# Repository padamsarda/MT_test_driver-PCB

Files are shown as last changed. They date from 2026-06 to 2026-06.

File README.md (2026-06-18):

# Magnetorquer Test PCB

## Overview
This PCB is designed to test different magnetorquer coils under varying operating conditions like voltage, current, and temperature.

The board uses an INA219 for current sensing and ADC voltage dividers for voltage measurement. 
It also has I²C and CAN headers so external sensors like magnetometers and temperature sensors can be connected if needed.

## Features
- DRV8871 motor driver
- INA219 current sensing
- ADC voltage measurement using voltage dividers
- USB Type-C interface
- SWD programming/debugging header
- I²C expansion header
- CAN header

## Applications
- Testing different magnetorquer coils
- Characterizing coil performance under different conditions
- Connecting external sensors for additional measurements
- Closed loop testing with magnetometers

## Notes
Designed and developed as part of **Team Anant**.

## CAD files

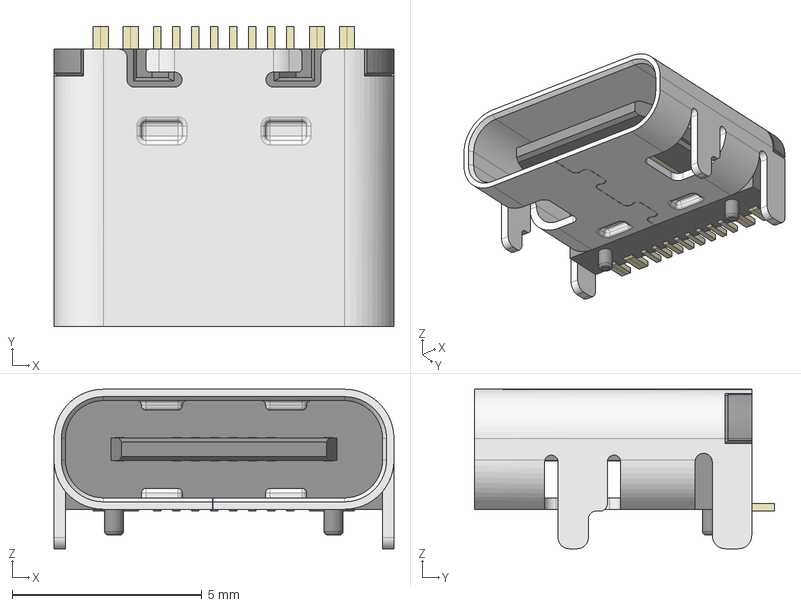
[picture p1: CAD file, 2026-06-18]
HRO_TYPE-C-31-M-12.step
8.95 x 7.90 x 4.20 mm

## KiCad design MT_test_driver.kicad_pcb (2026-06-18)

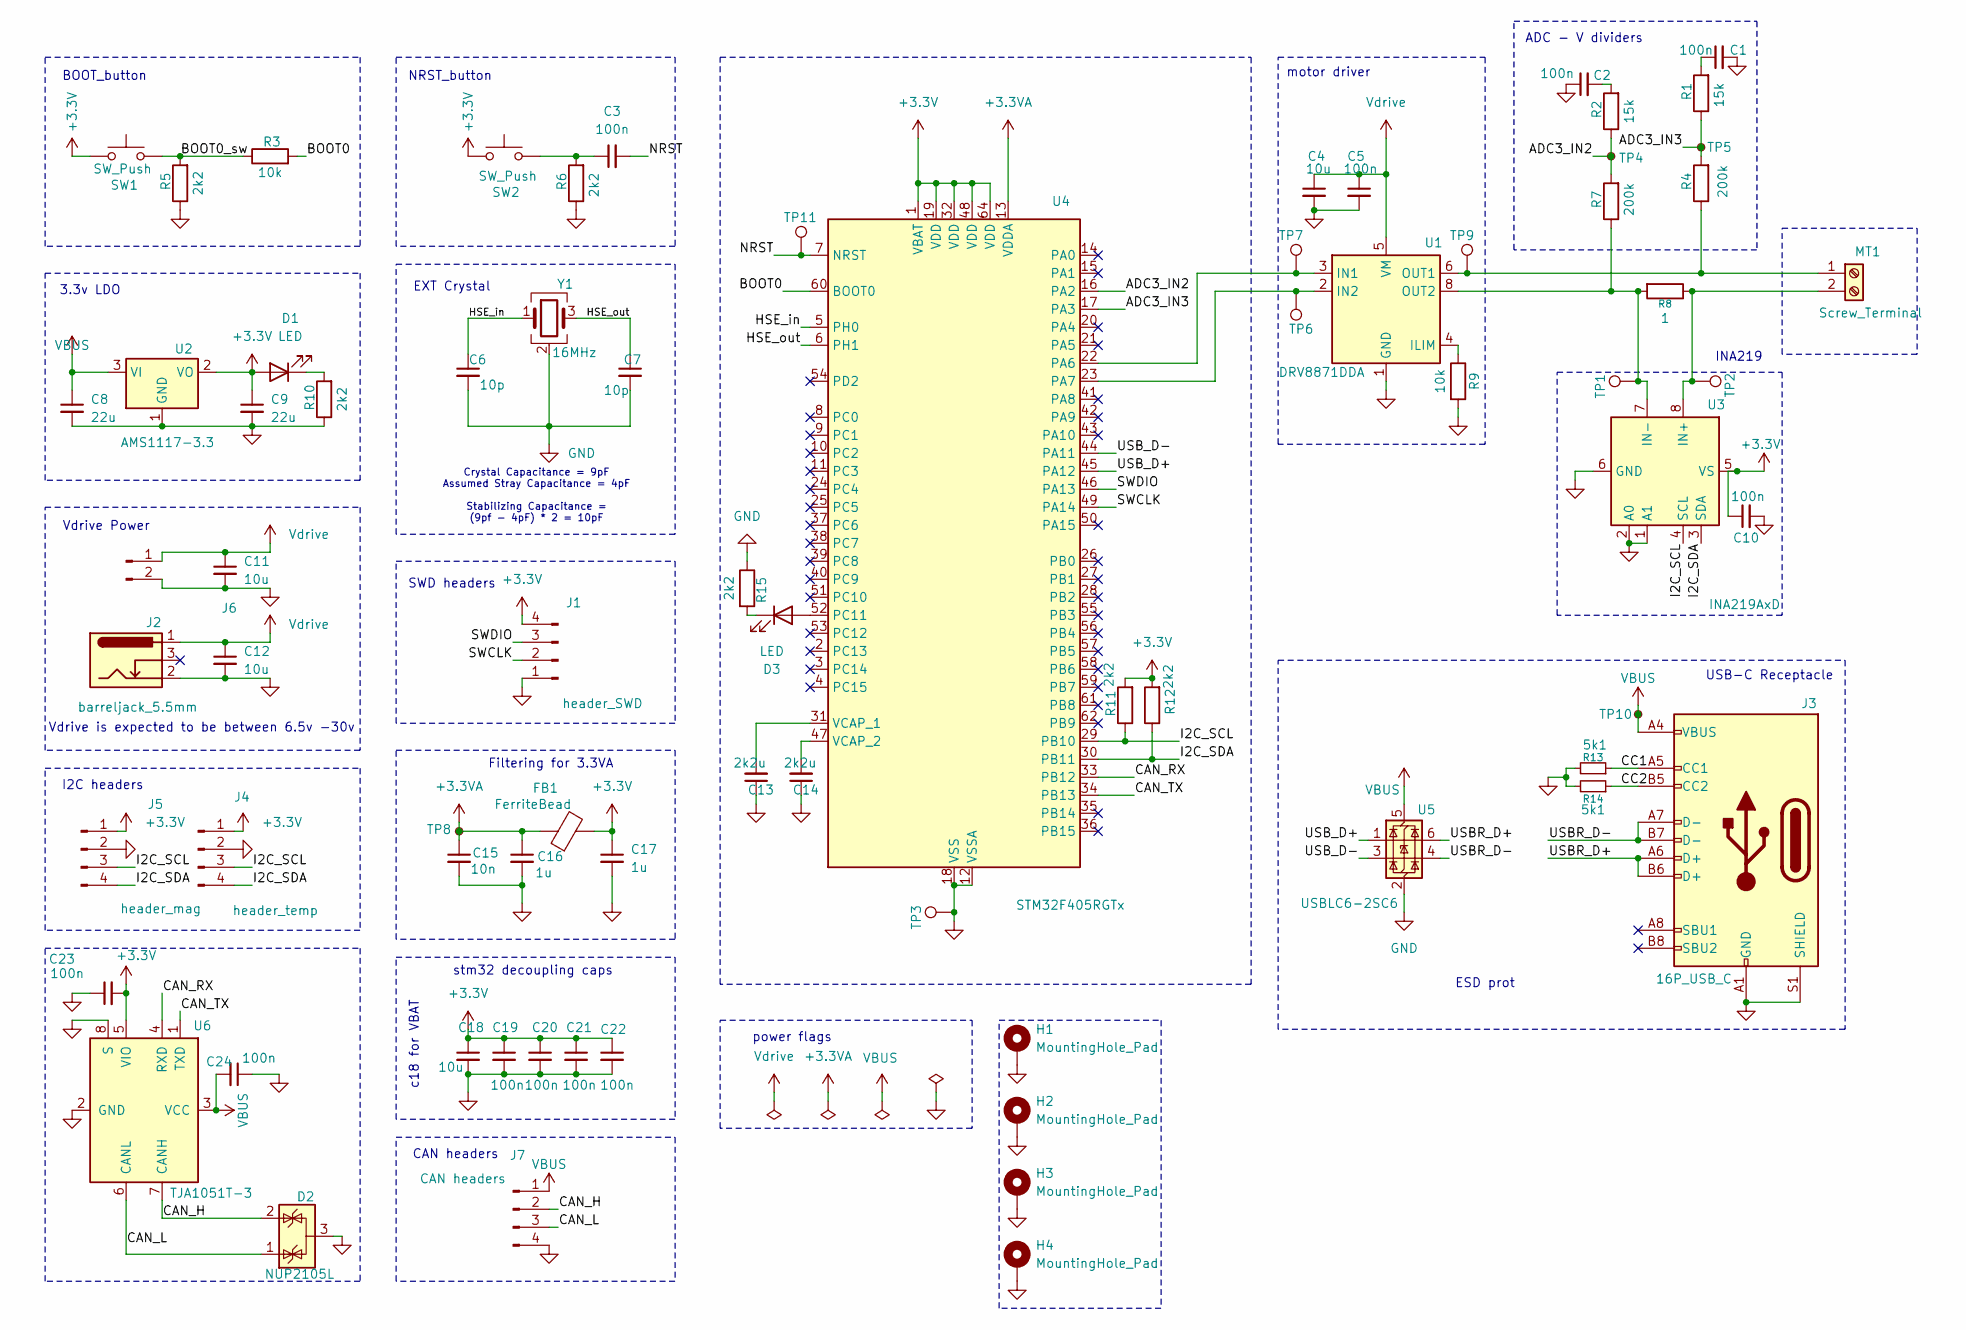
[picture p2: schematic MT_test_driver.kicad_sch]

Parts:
C1, C2, C3, C5, C10, C19, C20, C21, C22, C23, C24: 100n; C_0805_2012Metric_Pad1.18x1.45mm_HandSolder
C4, C11, C12, C18: 10u; C_0805_2012Metric_Pad1.18x1.45mm_HandSolder
C6, C7: 10p; C_0805_2012Metric_Pad1.18x1.45mm_HandSolder
C8, C9: 22u; C_0805_2012Metric_Pad1.18x1.45mm_HandSolder
C13, C14: 2k2u; C_0805_2012Metric_Pad1.18x1.45mm_HandSolder
C15: 10n; C_0805_2012Metric_Pad1.18x1.45mm_HandSolder
C16, C17: 1u; C_0805_2012Metric_Pad1.18x1.45mm_HandSolder
D1, D3: LED; LED_0805_2012Metric_Pad1.15x1.40mm_HandSolder
D2: NUP2105L; SOT-23
FB1: FerriteBead; L_0805_2012Metric_Pad1.05x1.20mm_HandSolder
H1, H2, H3, H4: MountingHole_Pad; MountingHole_2.2mm_M2_Pad
J1: header_SWD; PinHeader_1x04_P2.54mm_Vertical
J2: barreljack_5.5mm; BarrelJack_Horizontal
J3: 16P_USB_C; USB_C_Receptacle_G-Switch_GT-USB-7010ASV
J4: header_temp; PinHeader_1x04_P2.54mm_Vertical
J5: header_mag; PinHeader_1x04_P2.54mm_Vertical
J6: header_battery; PinHeader_1x02_P2.54mm_Vertical
J7: CAN headers; PinHeader_1x04_P2.54mm_Vertical
MT1: Screw_Terminal; TerminalBlock_Phoenix_MKDS-1,5-2-5.08_1x02_P5.08mm_Horizont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
R1, R2: 15k; R_0603_1608Metric_Pad0.98x0.95mm_HandSolder
R3, R9: 10k; R_0805_2012Metric_Pad1.20x1.40mm_HandSolder
R4, R7: 200k; R_0603_1608Metric_Pad0.98x0.95mm_HandSolder
R5, R6, R10, R11, R12, R15: 2k2; R_0805_2012Metric_Pad1.20x1.40mm_HandSolder
R8: 1; R_2512_6332Metric_Pad1.40x3.35mm_HandSolder
R13, R14: 5k1; R_0805_2012Metric_Pad1.20x1.40mm_HandSolder
SW1, SW2: SW_Push; tactile switch 4.5_4.5
TP1, TP2, TP3, TP6, TP7, TP9: TestPoint; PinHeader_1x01_P2.54mm_Vertical
TP4, TP5, TP8, TP10: TestPoint_Small; TestPoint_Pad_D1.5mm
TP11: TestPoint; TestPoint_Pad_D1.5mm
U1: DRV8871DDA; Texas_HTSOP-8-1EP_3.9x4.9mm_P1.27mm_EP2.95x4.9mm_Mask2.4x3.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
U2: AMS1117-3.3; SOT-223-3_TabPin2
U3: INA219AxD; SOIC-8_3.9x4.9mm_P1.27mm
U4: STM32F405RGTx; LQFP-64_10x10mm_P0.5mm
U5: USBLC6-2SC6; SOT-23-6
U6: TJA1051T-3; SOIC-8_3.9x4.9mm_P1.27mm
Y1: 16MHz; Crystal_SMD_3225-4Pin_3.2x2.5mm_HandSoldering

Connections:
+3.3V: C9.1, C10.1, C17.1, C18.1, C19.1, C20.1, C21.1, C22.1, C23.2, D1.2 (A), FB1.2, J1.4, J4.1, J5.1, R11.2, R12.2, SW1.1, SW2.1, U2.2 (VO), U3.5 (VS), U4.1 (VBAT), U4.19 (VDD), U4.32 (VDD), U4.48 (VDD), U4.64 (VDD), U6.5 (VIO)
+3.3VA: C15.1, C16.1, FB1.1, TP8.1, U4.13 (VDDA)
/ADC3_IN2: R2.1, R7.2, TP4.1, U4.16 (PA2)
/ADC3_IN3: R1.1, R4.2, TP5.1, U4.17 (PA3)
/BOOT0: R3.2, U4.60 (BOOT0)
/BOOT0_sw: R3.1, R5.2, SW1.2
/CAN_H: D2.2 (K), J7.2, U6.7 (CANH)
/CAN_L: D2.1 (K), J7.3, U6.6 (CANL)
/CAN_RX: U4.33 (PB12), U6.4 (RXD)
/CAN_TX: U4.34 (PB13), U6.1 (TXD)
/CC1: J3.A5 (CC1), R13.1
/CC2: J3.B5 (CC2), R14.1
/HSE_in: C6.1, U4.5 (PH0), Y1.1
/HSE_out: C7.1, U4.6 (PH1), Y1.3
/I2C_SCL: J4.3, J5.3, R11.1, U3.4 (SCL), U4.29 (PB10)
/I2C_SDA: J4.4, J5.4, R12.1, U3.3 (SDA), U4.30 (PB11)
/NRST: C3.2, TP11.1, U4.7 (NRST)
/SWCLK: J1.2, U4.49 (PA14)
/SWDIO: J1.3, U4.46 (PA13)
/USBR_D+: J3.A6 (D+), J3.B6 (D+), U5.6 (I/O1)
/USBR_D-: J3.A7 (D-), J3.B7 (D-), U5.4 (I/O2)
/USB_D+: U4.45 (PA12), U5.1 (I/O1)
/USB_D-: U4.44 (PA11), U5.3 (I/O2)
GND: C1.2, C2.1, C4.2, C5.2, C6.2, C7.2, C8.2, C9.2, C10.2, C11.2, C12.2, C13.1, C14.1, C15.2, C16.2, C17.2, C18.2, C19.2, C20.2, C21.2, C22.2, C23.1, C24.1, D2.3 (A), H1.1, H2.1, H3.1, H4.1, J1.1, J2.2, J3.A1 (GND), J3.A12 (GND), J3.B1 (GND), J3.B12 (GND), J3.S1 (SHIELD), J4.2, J5.2, J6.2, J7.4, R5.1, R6.1, R9.2, R10.1, R13.2, R14.2, R15.1, TP3.1, U1.1 (GND), U1.7 (GND), U1.9 (GND), U2.1 (GND), U3.1 (A1), U3.2 (A0), U3.6 (GND), U4.12 (VSSA), U4.18 (VSS), U4.63 (VSS), U5.2 (GND), U6.2 (GND), U6.8 (S), Y1.2 (G), Y1.4 (G)
unnamed: C1.1, R1.2
unnamed: C2.2, R2.2
unnamed: C3.1, R6.2, SW2.2
unnamed: D1.1 (K), R10.2
unnamed: D3.2 (A), U4.52 (PC11)
unnamed: D3.1 (K), R15.2
unnamed: MT1.1, R4.1, TP9.1, U1.6 (OUT1)
unnamed: MT1.2, R8.1, TP2.1, U3.8 (IN+)
unnamed: R9.1, U1.4 (ILIM)
unnamed: TP7.1, U1.3 (IN1), U4.22 (PA6)
unnamed: TP6.1, U1.2 (IN2), U4.23 (PA7)
unnamed: R7.1, R8.2, TP1.1, U1.8 (OUT2), U3.7 (IN-)
unnamed: C13.2, U4.31 (VCAP_1)
unnamed: C14.2, U4.47 (VCAP_2)
VBUS: C8.1, C24.2, J3.A4 (VBUS), J3.A9 (VBUS), J3.B4 (VBUS), J3.B9 (VBUS), J7.1, TP10.1, U2.3 (VI), U5.5 (VBUS), U6.3 (VCC)
Vdrive: C4.1, C5.1, C11.1, C12.1, J2.1, J6.1, U1.5 (VM)

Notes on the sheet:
EXT Crystal
SWD headers
Filtering for 3.3VA
NRST_button
motor driver
Vdrive is expected to be between 6.5v -30v
3.3v LDO
Vdrive Power
USB-C Receptacle
I2C headers
Crystal Capacitance = 9pF Assumed Stray Capacitance = 4pF Stabilizing Capacitance = (9pf - 4pF) * 2 = 10pF
ESD prot
CAN headers
BOOT_button
c18 for VBAT
power flags
stm32 decoupling caps
ADC - V dividers
INA219

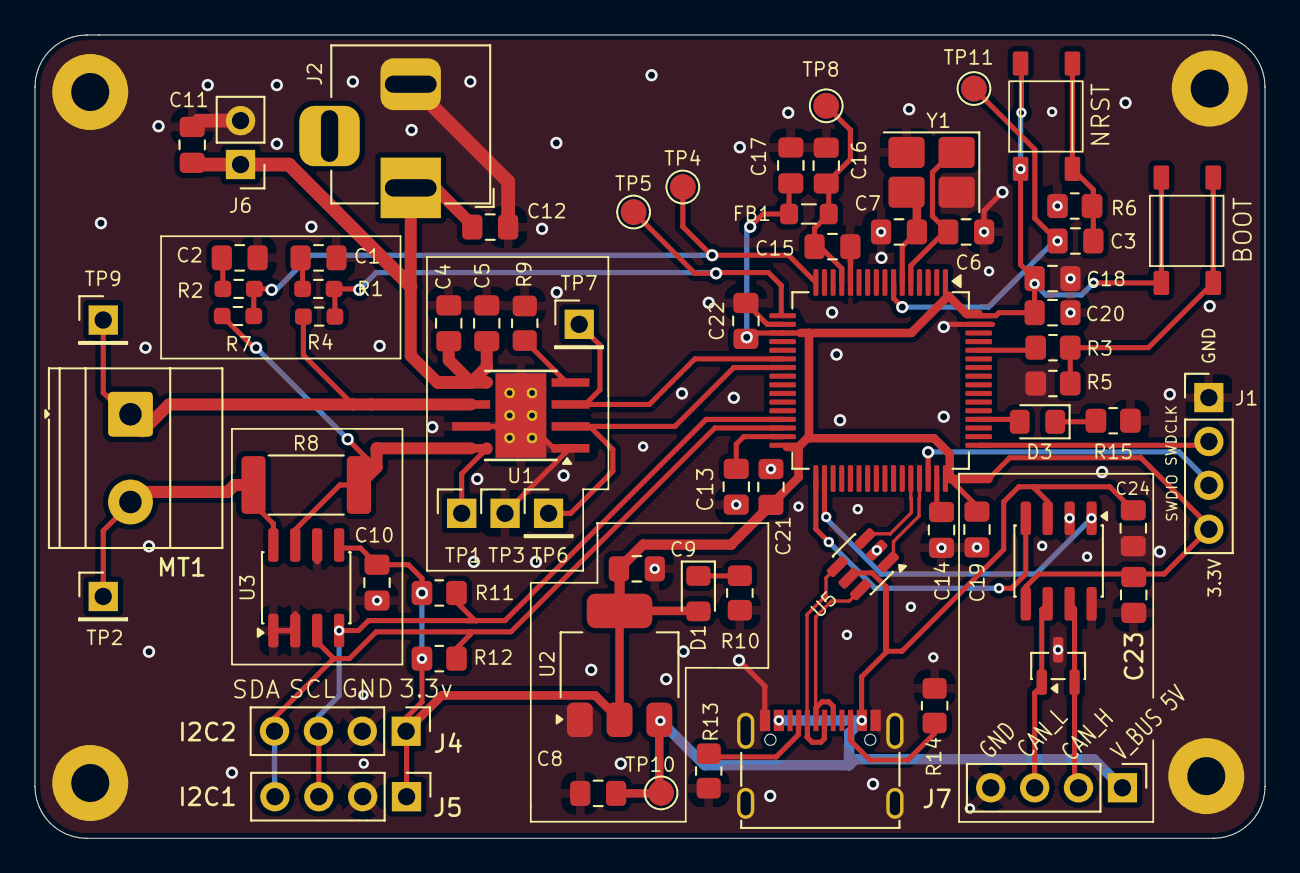
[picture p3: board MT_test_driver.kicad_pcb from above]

Board: 2 copper layers, 71.2 x 46.5 mm, 75 parts (0 on the bottom side), 40 nets.

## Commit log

2026-06-14 minor changes
    [MT_test_driver.kicad_pcb]
2026-06-16 pcb layout done, stm32 configuration changed etc
    [MT_test_driver.kicad_pcb, MT_test_driver.kicad_sch]
2026-06-16 Added CAN bus, other small changes
    [MT_test_driver.kicad_pcb, MT_test_driver.kicad_sch]
2026-06-17 changes in layout , moving components
    [MT_test_driver.kicad_pcb, MT_test_driver.kicad_sch]
2026-06-18 final changes
    [HRO_TYPE-C-31-M-12.step, MT_test_driver.kicad_pcb, MT_test_driver.kicad_sch]
2026-06-18 added gpio LED for debugging
    [MT_test_driver.kicad_pcb, MT_test_driver.kicad_sch]
